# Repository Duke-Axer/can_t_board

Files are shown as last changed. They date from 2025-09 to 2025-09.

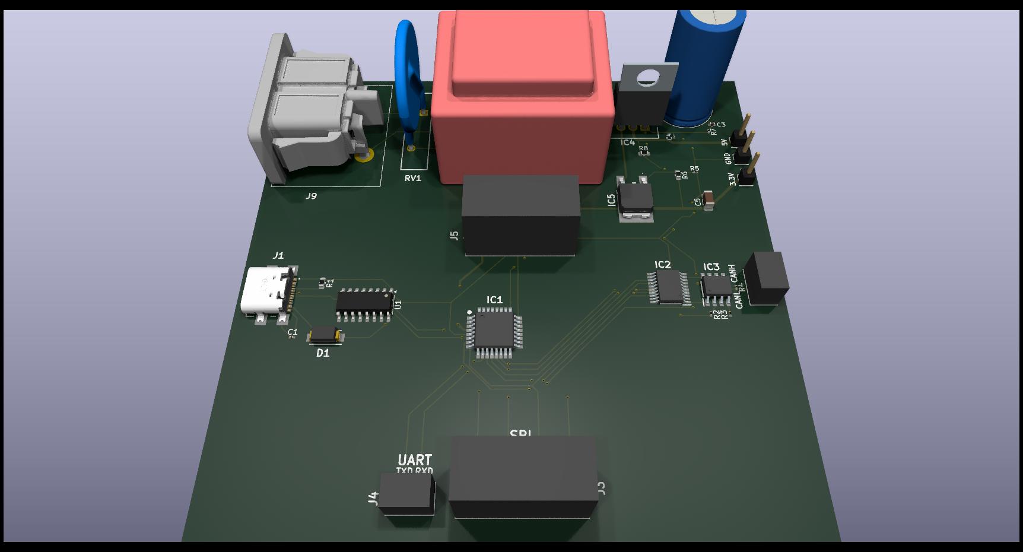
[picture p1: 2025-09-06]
CAN_t_b.jpg

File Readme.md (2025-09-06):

**Jest to płytka (10 × 10 cm) z procesorem Cortex M0+, zaprojektowana do testów urządzeń komunikujących się przez różne interfejsy.**

## Główne cechy:

**Procesor:** ARM Cortex M0+
**Interfejsy komunikacyjne:**
- SWD (Serial Wire Debug) – programowanie i debugowanie
- SPI (Serial Peripheral Interface)
- UART (Universal Asynchronous Receiver/Transmitter)
- CAN (Controller Area Network)
- USB (Device mode)

**Zasilanie:**
- Wbudowana przetwornica AC/DC
- Zasilanie z gniazda 230 VAC
- Wbudowane napięcia wyjściowe: 5 V i 3.3 V

**Wymiary PCB:** 10 × 10 cm  
**Symulacje:** Przetwornica została zasymulowana w LTspice.  
/projekt  
  ├─ ltspice/         # Symulacje przetwornicy w LTspice  
  ├─ Lib_CAN/      	  # Biblioteka z modelami dla Kicad  
  ├─ BOM/             # Lista użytych footprintów  
  ├─ README.md        # Ten plik  
  └─ CAN_t_b.jpg      # Obraz z widoku 3D

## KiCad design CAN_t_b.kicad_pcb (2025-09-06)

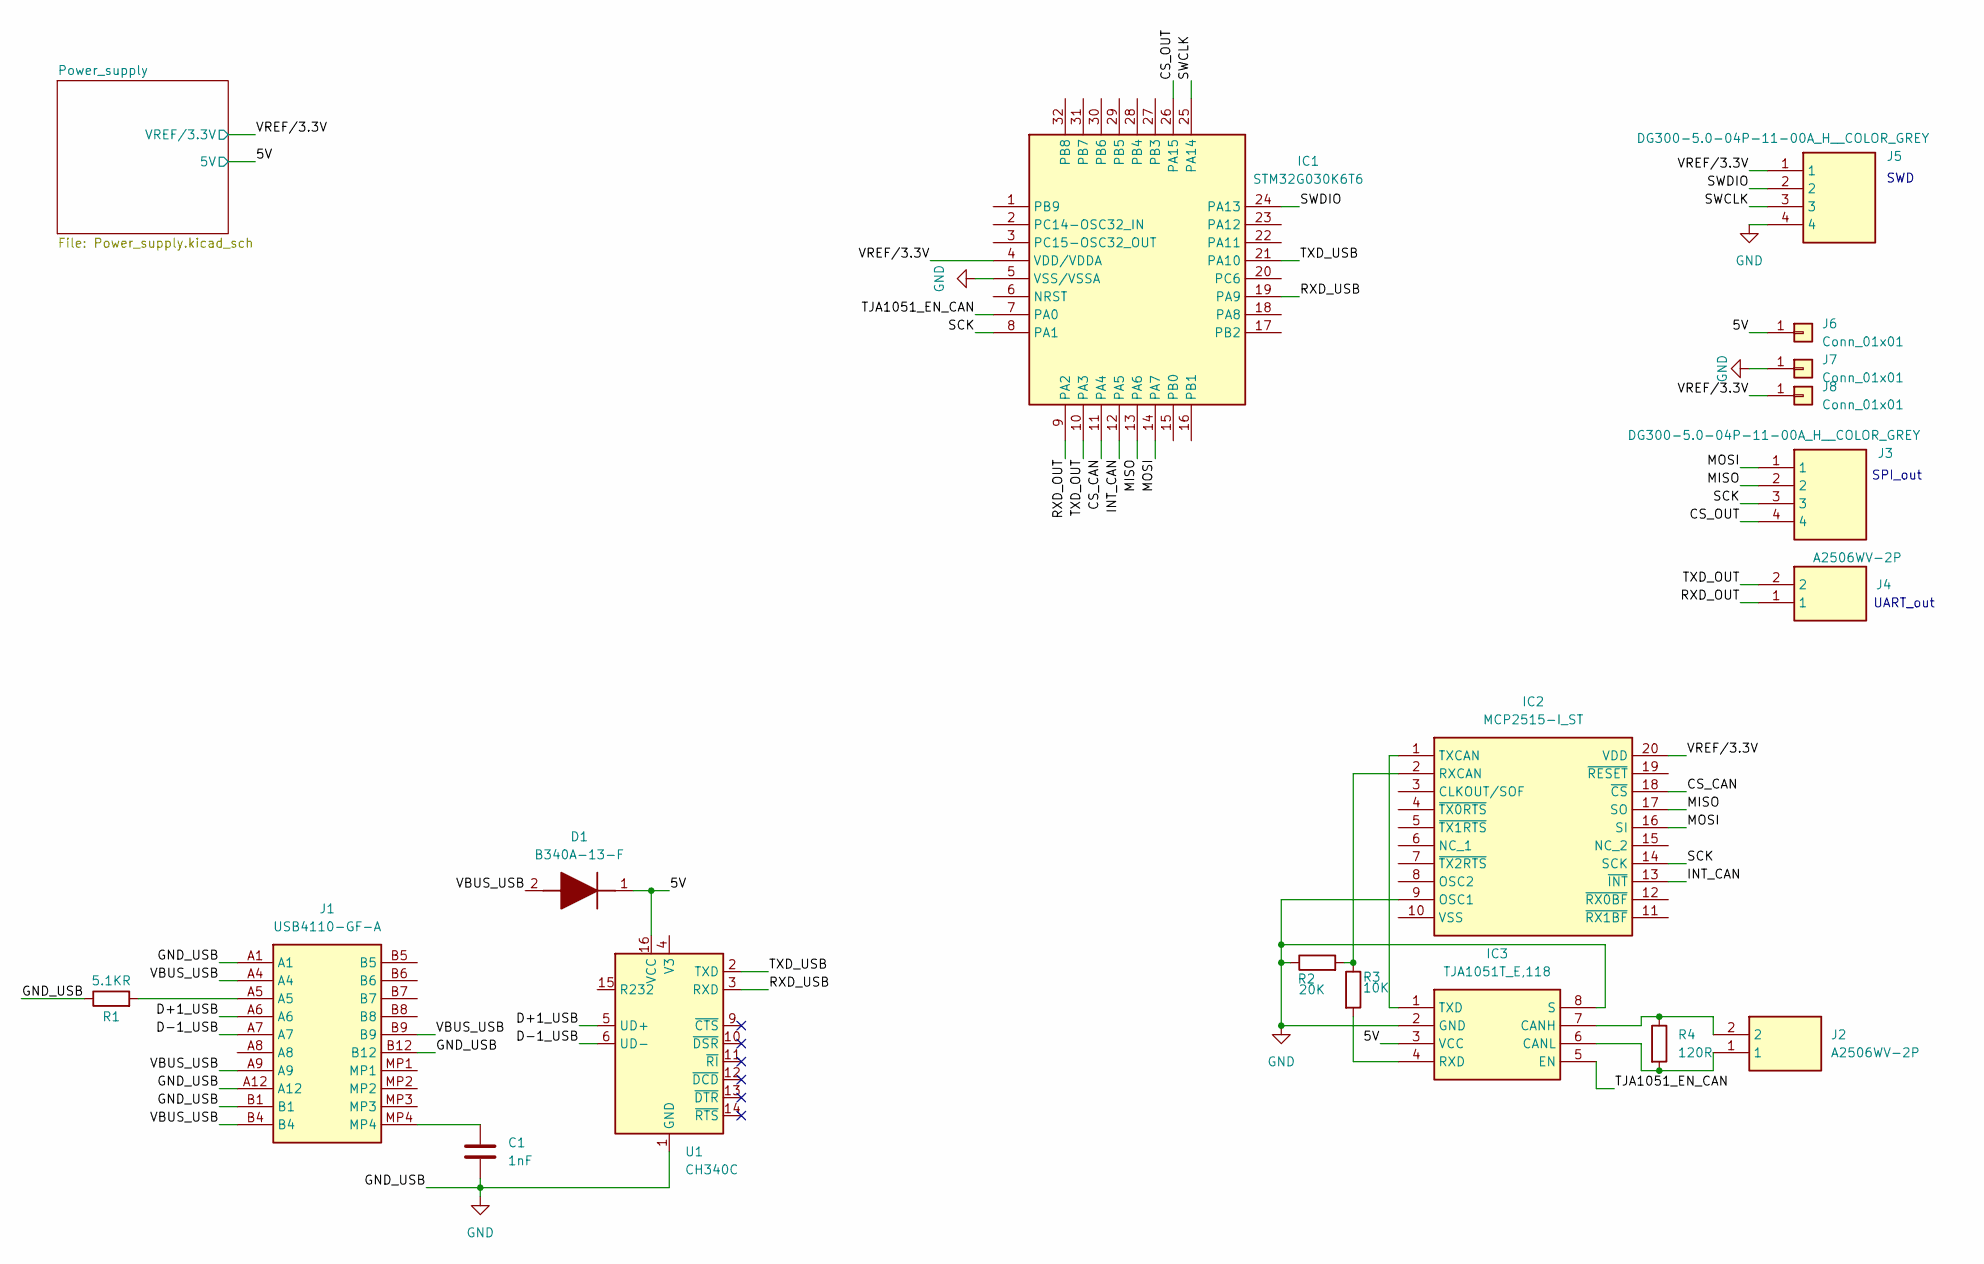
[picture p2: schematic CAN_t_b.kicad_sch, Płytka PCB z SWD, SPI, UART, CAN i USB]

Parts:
C1: 1nF; C_0201_0603Metric
D1: B340A-13-F; DIOM5226X240N; Manufacturer_Part_Number B340A-13-F
IC1: STM32G030K6T6; QFP80P900X900X160-32N; Manufacturer_Part_Number STM32G030K6T6
IC2: MCP2515-I_ST; SOP65P640X120-20N; Mouser Part Number 579-MCP2515-I/ST
IC3: TJA1051T_E,118; SOIC127P600X175-8N; Manufacturer_Part_Number TJA1051T/E,118
J1: USB4110-GF-A; USB4110GFA; Manufacturer_Part_Number USB4110-GF-A
J2, J4: A2506WV-2P; A2506WV2P; Manufacturer_Part_Number A2506WV-2P
J3, J5: DG300-5.0-04P-11-00A_H__COLOR_GREY; DG3005004P1100AHCOLORGREY; Manufacturer_Part_Number DG300-5.0-04P-11-00A(H) COLOR GREY
J6, J7, J8: Conn_01x01; PinHeader_1x01_P2.54mm_Vertical
R1: 5.1KR; R_0603_1608Metric
R2: 20K; R_0201_0603Metric
R3: 10K; R_0201_0603Metric
R4: 120R; R_0201_0603Metric
U1: CH340C; SOIC-16_3.9x9.9mm_P1.27mm

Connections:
/5V: D1.1 (K), IC3.3 (VCC), J6.1, U1.16 (VCC); also elsewhere on the board
/CS_CAN: IC1.11 (PA4), IC2.18 (~CS)
/CS_OUT: IC1.26 (PA15), J3.4
/D+1_USB: J1.A6, U1.5 (UD+)
/D-1_USB: J1.A7, U1.6 (UD-)
/INT_CAN: IC1.12 (PA5), IC2.13 (~INT)
/MISO: IC1.13 (PA6), IC2.17 (SO), J3.2
/MOSI: IC1.14 (PA7), IC2.16 (SI), J3.1
/RXD_OUT: IC1.9 (PA2), J4.1
/RXD_USB: IC1.19 (PA9), U1.3 (RXD)
/SCK: IC1.8 (PA1), IC2.14 (SCK), J3.3
/SWCLK: IC1.25 (PA14), J5.3
/SWDIO: IC1.24 (PA13), J5.2
/TJA1051_EN_CAN: IC1.7 (PA0), IC3.5 (EN)
/TXD_OUT: IC1.10 (PA3), J4.2
/TXD_USB: IC1.21 (PA10), U1.2 (TXD)
/VBUS_USB: D1.2 (A), J1.A4, J1.A9, J1.B4, J1.B9
/VREF/3.3V: IC1.4 (VDD/VDDA), IC2.20 (VDD), J5.1, J8.1; also elsewhere on the board
GND: C1.2, IC1.5 (VSS/VSSA), IC2.9 (OSC1), IC3.2 (GND), IC3.8 (S), J1.A1, J1.A12, J1.B1, J1.B12, J5.4, J7.1, R1.1, R2.1, U1.1 (GND); also elsewhere on the board
unnamed: C1.1, J1.MP4
unnamed: IC2.2 (RXCAN), R2.2, R3.1
unnamed: IC2.1 (TXCAN), IC3.1 (TXD)
unnamed: IC3.7 (CANH), J2.2, R4.1
unnamed: IC3.6 (CANL), J2.1, R4.2
unnamed: IC3.4 (RXD), R3.2
unnamed: J1.A5, R1.2

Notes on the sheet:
UART_out
SWD
SPI_out

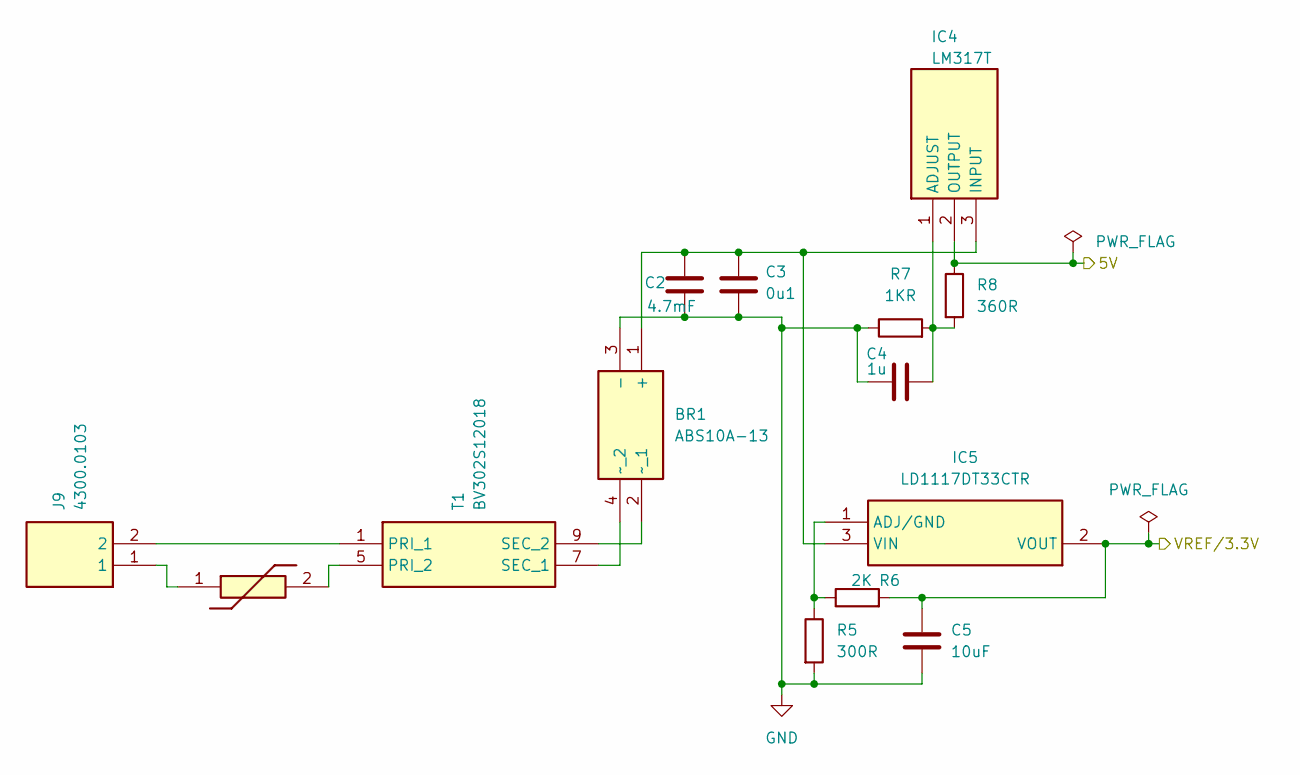
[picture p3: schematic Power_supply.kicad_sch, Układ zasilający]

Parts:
BR1: ABS10A-13; ABS10A13; Manufacturer_Part_Number ABS10A-13
C2: 4.7mF; C_Radial_D12.5mm_H25.0mm_P5.00mm
C3: 0u1; C_0402_1005Metric
C4: 1u; C_0201_0603Metric
C5: 10uF; C_1206_3216Metric
IC4: LM317T; TO255P460X1020X2008-3P; Manufacturer_Part_Number LM317T
IC5: LD1117DT33CTR; Manufacturer_Part_Number LD1117DT33CTR
J9: 4300.0103; 43000103; Manufacturer_Part_Number 4300.0103
R5: 300R; R_0201_0603Metric
R6: 2K; R_0603_1608Metric
R7: 1KR; R_0201_0603Metric
R8: 360R; R_0603_1608Metric
RV1: B72220S0271K101; Manufacturer_Part_Number B72220S0271K101
T1: BV302S12018; Manufacturer_Part_Number BV302S12018

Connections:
/5V: IC4.2 (OUTPUT), R8.1; also elsewhere on the board
/VREF/3.3V: C5.1, IC5.2 (VOUT), R6.2; also elsewhere on the board
GND: BR1.3 (-), C2.2, C3.2, C4.1, C5.2, R5.2, R7.1; also elsewhere on the board
unnamed: BR1.1 (+), C2.1, C3.1, IC4.3 (INPUT), IC5.3 (VIN)
unnamed: BR1.2 (~_1), T1.9 (SEC_2)
unnamed: BR1.4 (~_2), T1.7 (SEC_1)
unnamed: C4.2, IC4.1 (ADJUST), R7.2, R8.2
unnamed: IC5.1 (ADJ/GND), R5.1, R6.1
unnamed: J9.1, RV1.1
unnamed: J9.2, T1.1 (PRI_1)
unnamed: RV1.2, T1.5 (PRI_2)

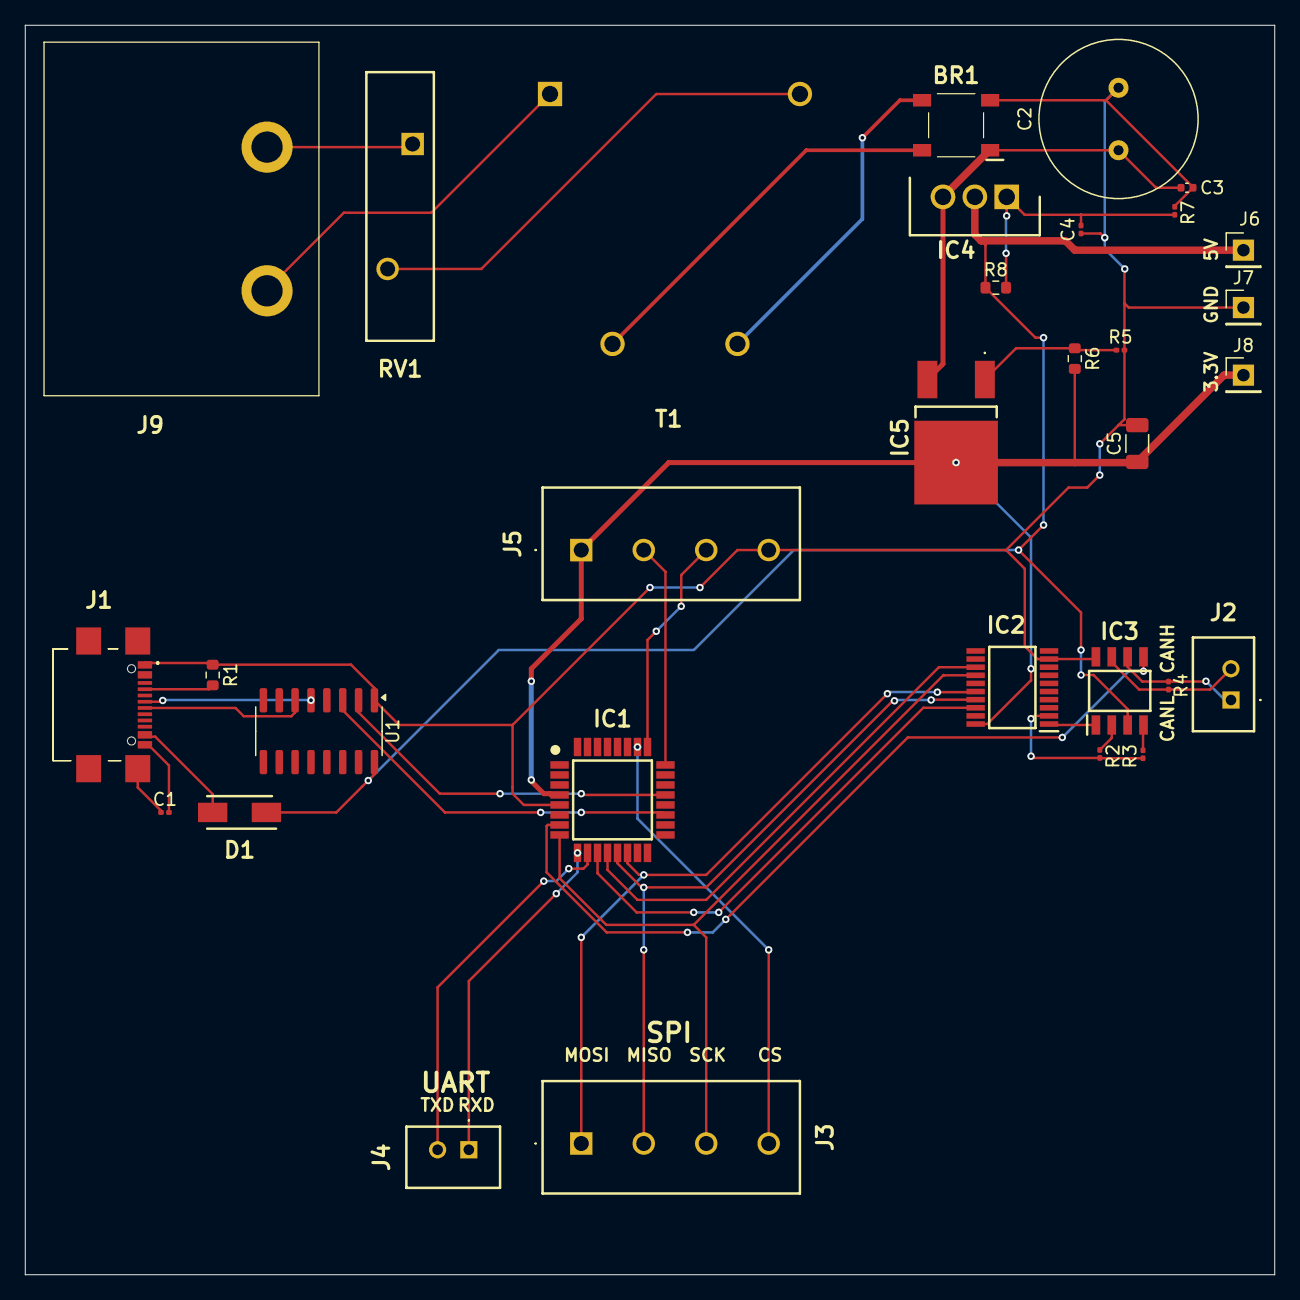
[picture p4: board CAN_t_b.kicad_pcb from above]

Board: 2 copper layers, 100.0 x 100.0 mm, 32 parts (1 on the bottom side), 34 nets.
